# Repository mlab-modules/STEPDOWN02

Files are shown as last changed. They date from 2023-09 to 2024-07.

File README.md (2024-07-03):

# STEPDOWN02 - 1MHz switching down converter

This repository contains the design files, documentation, and usage instructions for the TPS54332 MLAB module. The TPS54332 is a high-efficiency synchronous buck converter capable of delivering up to 3 A of continuous output current. This development module is designed to integrate the TPS54332 into MLAB projects with ease.

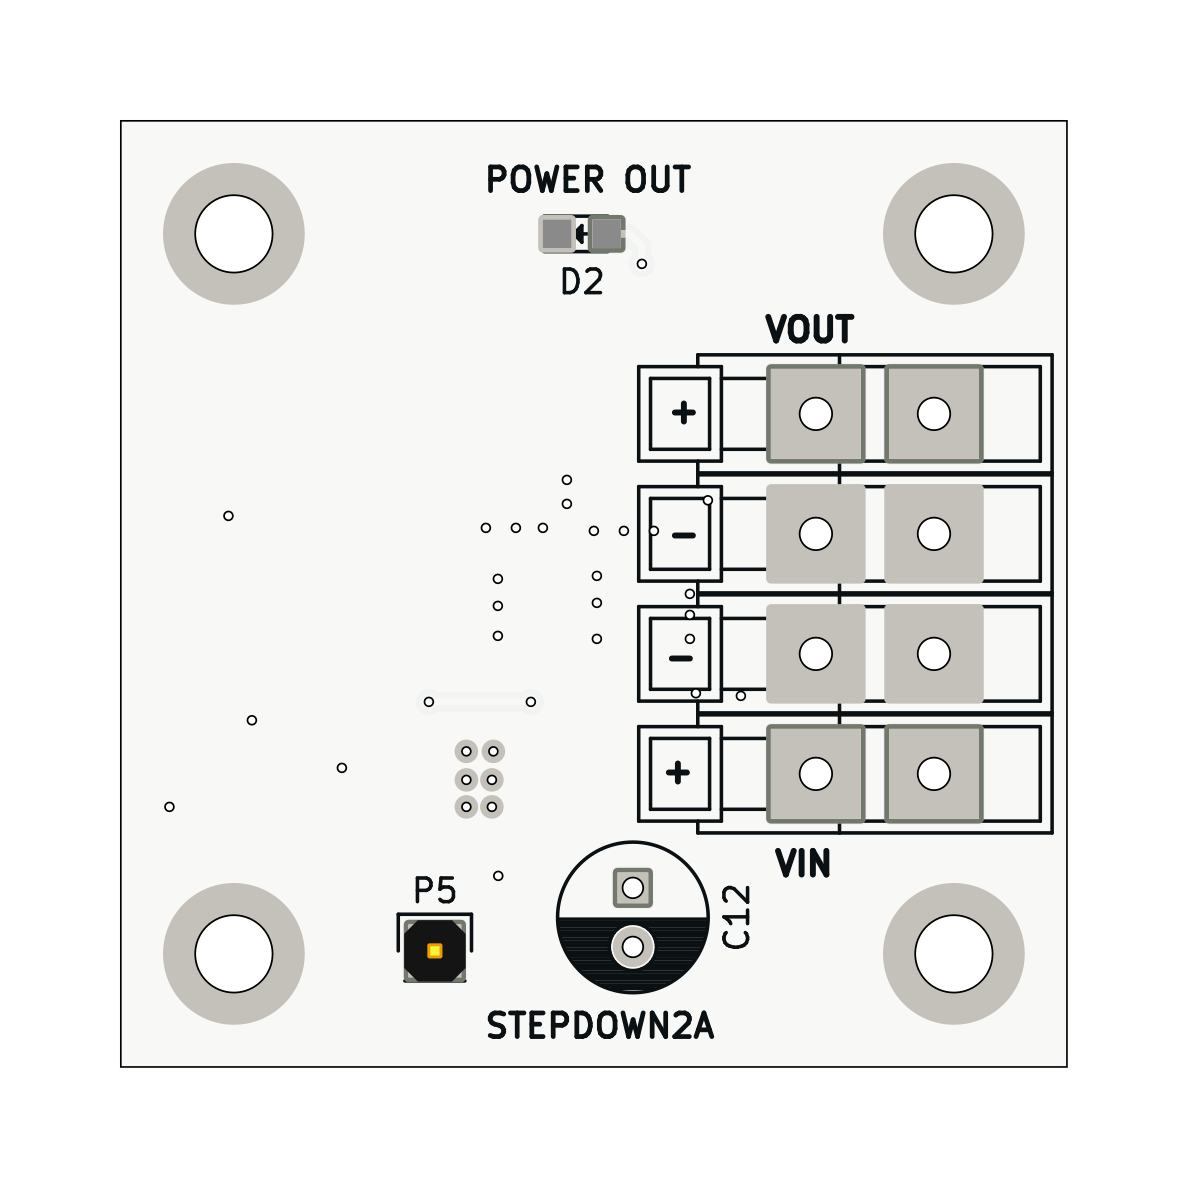
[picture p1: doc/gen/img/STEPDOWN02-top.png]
STEPDOWN02 top view
 

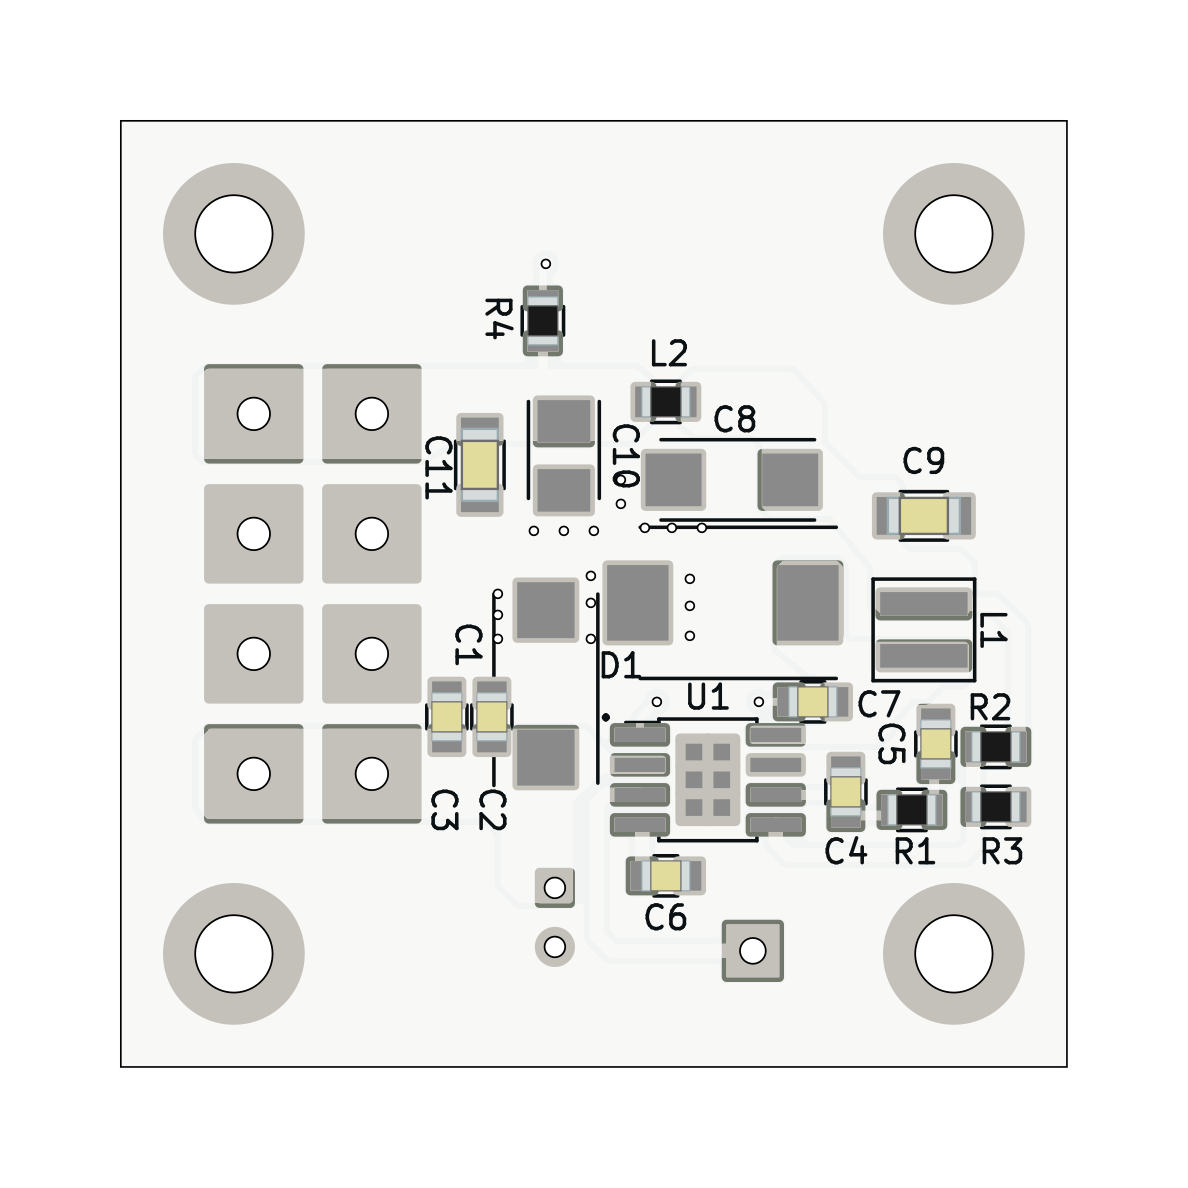
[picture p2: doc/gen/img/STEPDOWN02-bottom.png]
STEPDOWN02 bottom veiw
 

## Features

- **Input Voltage Range**: 3.5 V to 28 V
- **Output Voltage Range**: 0.8 V to 23 V
- **Output Current**: Up to 3 A
- **Efficiency**: Up to 95%
- **Switching Frequency**: Adjustable up to 2 MHz
- **Integrated High-Side and Low-Side MOSFETs**
- **Cycle-by-Cycle Current Limit, Frequency Fold Back and Thermal Shutdown Protection**

## Getting Started

### Prerequisites

To use this development module, you will need:

- A DC power supply (3.5 V to 28 V)
- Load device (up to 3 A)
- Multimeter or oscilloscope for measurements
- Soldering equipment (if customization of output voltage is needed)

### Installation

1. **Connect the Power Supply**: Connect the positive terminal of your DC power supply to the VIN pin and the negative terminal to the GND pin of the module.
2. **Connect the Load**: Connect your load device between the VOUT pin and GND pin of the module.

### Usage

1. **Adjust Output Voltage**: The output voltage can be adjusted by selecting appropriate values for the feedback resistors (R1 and R2). Refer to the datasheet for the resistor calculation formula.
2. **Monitoring**: Use a multimeter or oscilloscope to monitor the output voltage and current.
3. **Optimization**: Fine-tune the switching frequency and compensation network as required for your application.

## Documentation

- **Datasheet**: [TPS54332 Datasheet](https://www.ti.com/product/TPS54332)

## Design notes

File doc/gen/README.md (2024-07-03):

# PCB

Board size: 40.13x40.13 mm (1.58x1.58 inches)

- This is the size of the rectangle that contains the board
- Thickness: 1.6 mm (63 mils)
- Material: FR4
- Finish: HAL
- Layers: 2
- Copper thickness: 35 µm

Solder mask: TOP / BOTTOM

- Color: Green

Silk screen: TOP / BOTTOM

- Color: White

# Important sizes

Clearance: 0.15 mm (6 mils)

Track width: 0.3 mm (12 mils)

- By design rules: 0.2 mm (8 mils)

Drill: 0.4 mm (16 mils)

- Vias: 0.4 mm (16 mils) [Design: 0.4 mm (16 mils)]
- Pads: 0.4 mm (16 mils)
- The above values are real drill sizes, they add 0.1 mm (4 mils) to plated holes (PTH)

Via: 0.6/0.3 mm (24/12 mils)

- By design rules: 0.4/0.3 mm (16/12 mils)
- Micro via: yes [0.2/0.1 mm (8/4 mils)]
- Buried/blind via: yes
- Total: 28 (thru: 28 buried/blind: 0 micro: 0)

Outer Annular Ring: 0.1 mm (4 mils)

- By design rules: 0.1 mm (4 mils)

Eurocircuits class: 6C
- Using min drill 0.35 mm for an OAR of 0.13 mm

# General stats

Components count: (SMD/THT)

- Top: 1/10 (SMD + THT)
- Bottom: 19/0 (SMD)

Defined tracks:

- 0.4 mm (16 mils)
- 0.5 mm (20 mils)
- 0.6 mm (24 mils)
- 0.8 mm (31 mils)
- 1.0 mm (39 mils)
- 1.5 mm (59 mils)
- 2.0 mm (79 mils)
- 2.5 mm (98 mils)

Used tracks:

- 0.3 mm (12 mils) (39) defined: no
- 0.4 mm (16 mils) (12) defined: yes
- 0.5 mm (20 mils) (1) defined: yes
- 0.6 mm (24 mils) (34) defined: yes
- 1.0 mm (39 mils) (14) defined: yes
- 1.5 mm (59 mils) (1) defined: yes
- 2.5 mm (98 mils) (2) defined: yes

Defined vias:

Used vias:

- 0.6/0.3 mm (24/12 mils) (Count: 28, Aspect: 2.7 A) defined: no

Holes (excluding vias):

- 0.3 mm (12 mils) (6)
- 0.8 mm (31 mils) (2)
- 1.02 mm (40 mils) (1)
- 1.3 mm (51 mils) (8)
- 3.2 mm (126 mils) (4)

Oval holes:

Drill tools (including vias and computing adjusts and rounding):

- 0.4 mm (16 mils) (34)
- 0.9 mm (35 mils) (2)
- 1.1 mm (43 mils) (1)
- 1.4 mm (55 mils) (8)
- 3.3 mm (130 mils) (4)

Solder paste stats:

Using a paste with 87.75 % alloy, that has an specific gravity for the alloy of 7.4 g/cm³
and 1.0 g/cm³ for the flux. This paste has an specific gravity of  4.15 g/cm³.

The stencil thickness is  0.12 mm.

| Side | Pads with paste | Area [mm²] | Paste [g] |
|---|---|---|---|
| Top | 2 | 2.87 | 0.01 |
| Bottom | 50 | 103.27 | 0.51 |
| Total  | 52 | 106.14 | 0.53 |

Note: this is just an approximation to the theoretical value. Margins of the solder mask and waste aren't computed.

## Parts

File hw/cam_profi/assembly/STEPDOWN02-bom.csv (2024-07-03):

Component | Description | Part | References | Value | Footprint | Quantity Per PCB | Datasheet
1 |  | C | C4 | 18pF | C_0805 | 1
2 |  | C | C5 | 680pF | C_0805 | 1
3 |  | C | C6 | 8n2 | C_0805 | 1
4 |  | C | C7 | 100n | C_0805 | 1
5 |  | C | C3 | 1u | C_0805 | 1
6 |  | C | C9C11 | 1u5 | C_1206 | 2
7 |  | C | C2 | 3u3 | C_0805 | 1
8 |  | CP | C1 | 22u | TantalC_SizeD_EIA-7343_Reflow | 1
9 |  | CP | C10 | 22u | TantalC_SizeB_EIA-3528_Reflow | 1
10 |  | CP | C8 | 22u | TantalC_SizeC_EIA-6032_Reflow | 1
11 |  | CP | C12 | 47u | C_Radial_D6.3_L11.2_P2.5 | 1
12 |  | D_Schottky | D1 | D_Schottky | DO-214AB | 1
13 |  | Led_Small | D2 | POWER OUT | LED_0805 | 1
14 |  | CONN1_1 | J1J2J3J4 | CONN1_1 | WAGO256 | 4
15 |  | INDUCTOR | L2 | 240nH | R_0805 | 1
16 |  | INDUCTOR | L1 | 4.7uH | Inductor_XAL4030-472MEB | 1
17 |  | CONN_01X01 | P5 | CONN_01X01 | Pin_Header_Straight_1x01 | 1
18 |  | R | R4 | 1k2 | R_0805 | 1
19 |  | R | R3 | 1k93 | R_0805 | 1
20 |  | R | R2 | 10k2 | R_0805 | 1
21 |  | R | R1 | 35k7 | R_0805 | 1
22 |  | TPS54332 | U1 | TPS54332 | 8-PowerSOIC_Pitch1.27mm | 1 | https://www.ti.com/lit/ds/symlink/tps54332.pdf?ts=1720015286104

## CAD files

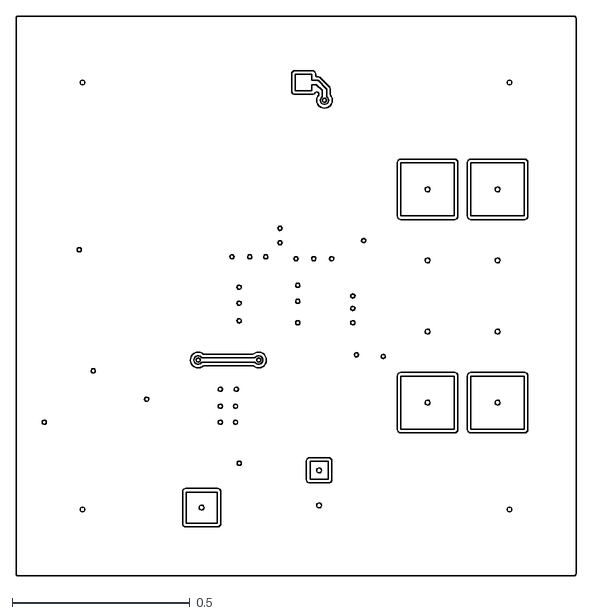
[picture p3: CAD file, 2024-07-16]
doc/gen/dxf/STEPDOWN02-F_Cu.dxf
1.57 x 1.57

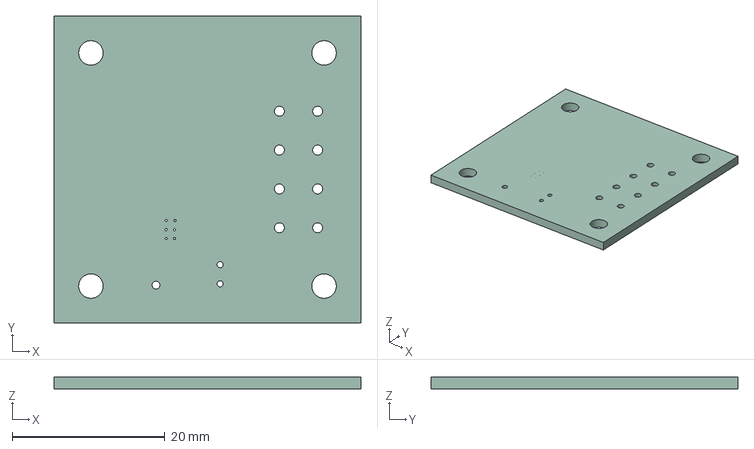
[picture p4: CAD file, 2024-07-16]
doc/gen/STEPDOWN02.step
40.1 x 40.1 x 1.60 mm

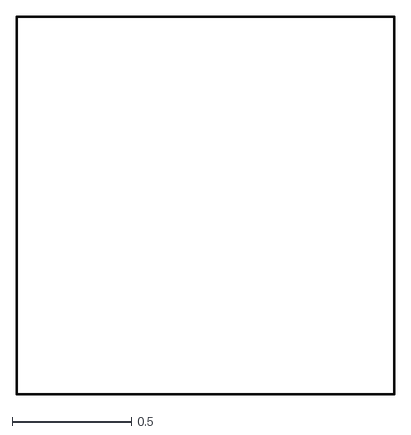
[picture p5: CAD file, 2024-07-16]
doc/gen/dxf/STEPDOWN02-Edge_Cuts.dxf
1.59 x 1.59

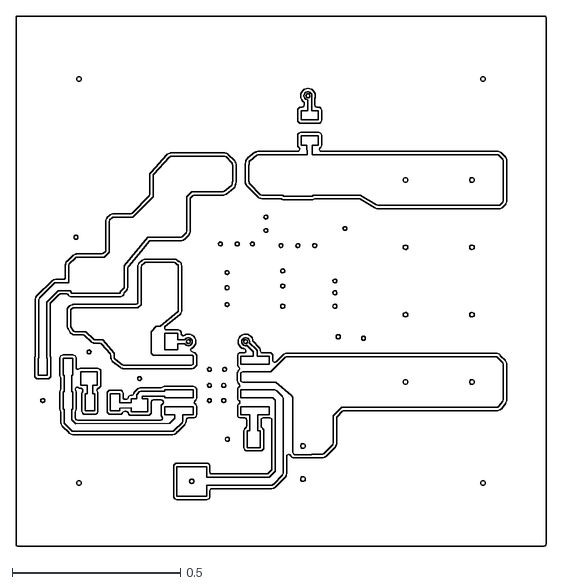
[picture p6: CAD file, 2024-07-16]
doc/gen/dxf/STEPDOWN02-B_Cu.dxf
1.57 x 1.57

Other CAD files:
doc/gen/dxf/STEPDOWN02-User_Drawings.dxf
doc/gen/dxf/STEPDOWN02-B_Mask.dxf
doc/gen/dxf/STEPDOWN02-B_Paste.dxf
doc/gen/dxf/STEPDOWN02-B_Silkscreen.dxf
doc/gen/dxf/STEPDOWN02-F_Mask.dxf
doc/gen/dxf/STEPDOWN02-F_Paste.dxf
doc/gen/dxf/STEPDOWN02-F_Silkscreen.dxf

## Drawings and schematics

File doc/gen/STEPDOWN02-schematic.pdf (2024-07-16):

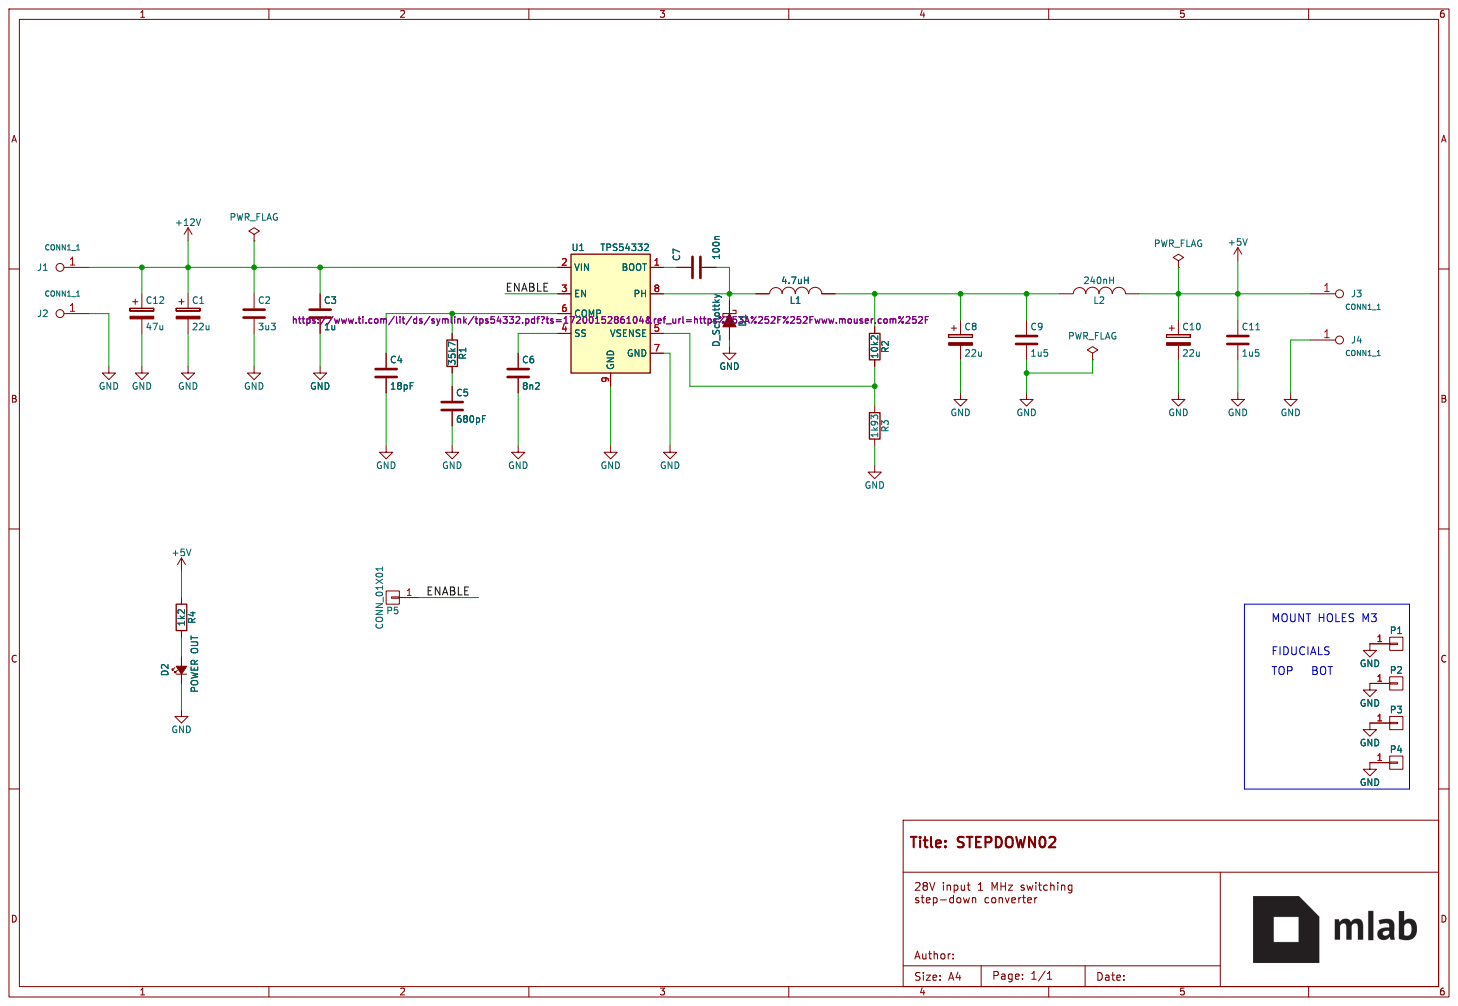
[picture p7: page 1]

https://www.ti.com/lit/ds/symlink/tps54332.pdf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 D1 D_Schottky GND

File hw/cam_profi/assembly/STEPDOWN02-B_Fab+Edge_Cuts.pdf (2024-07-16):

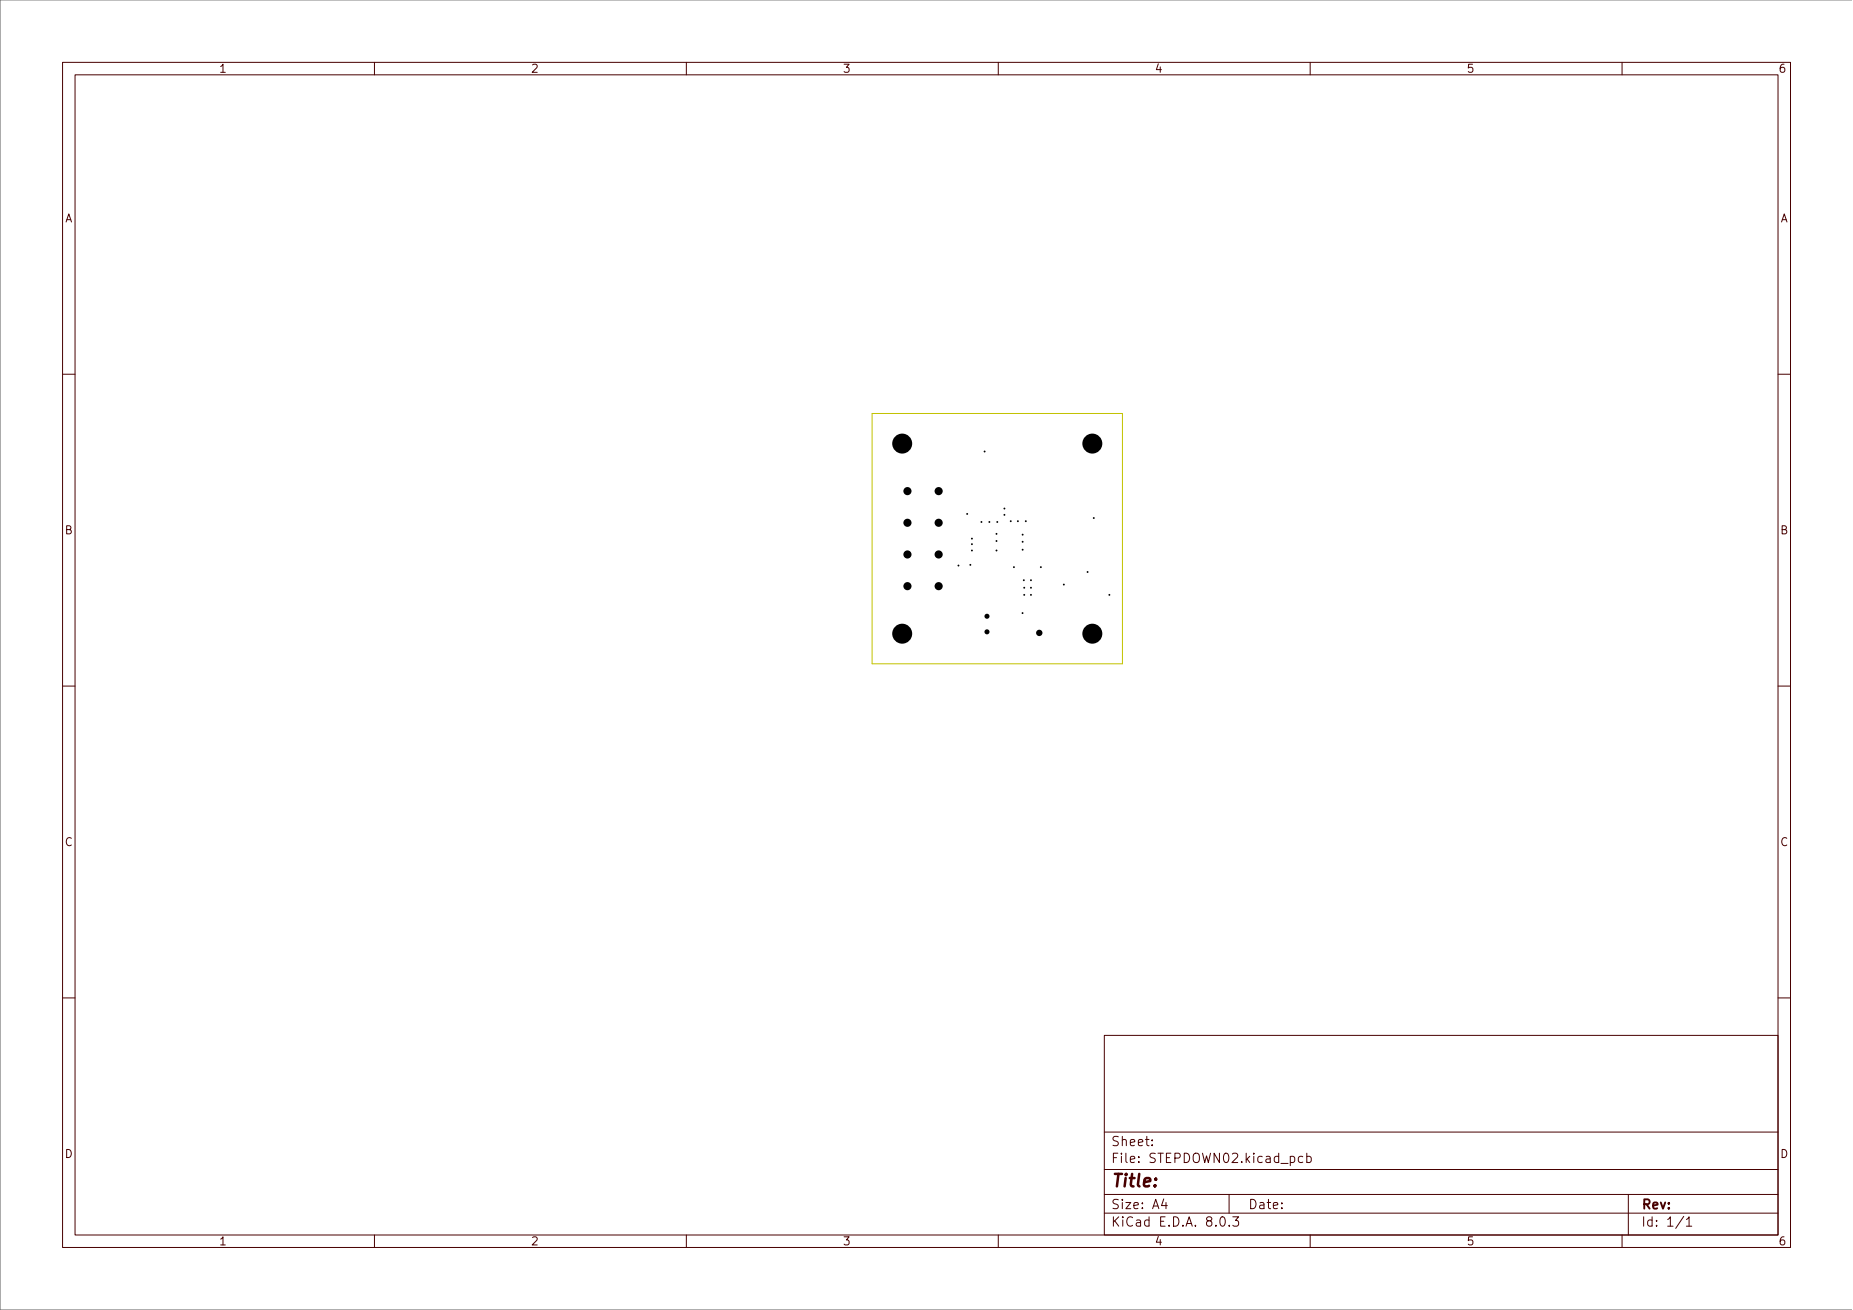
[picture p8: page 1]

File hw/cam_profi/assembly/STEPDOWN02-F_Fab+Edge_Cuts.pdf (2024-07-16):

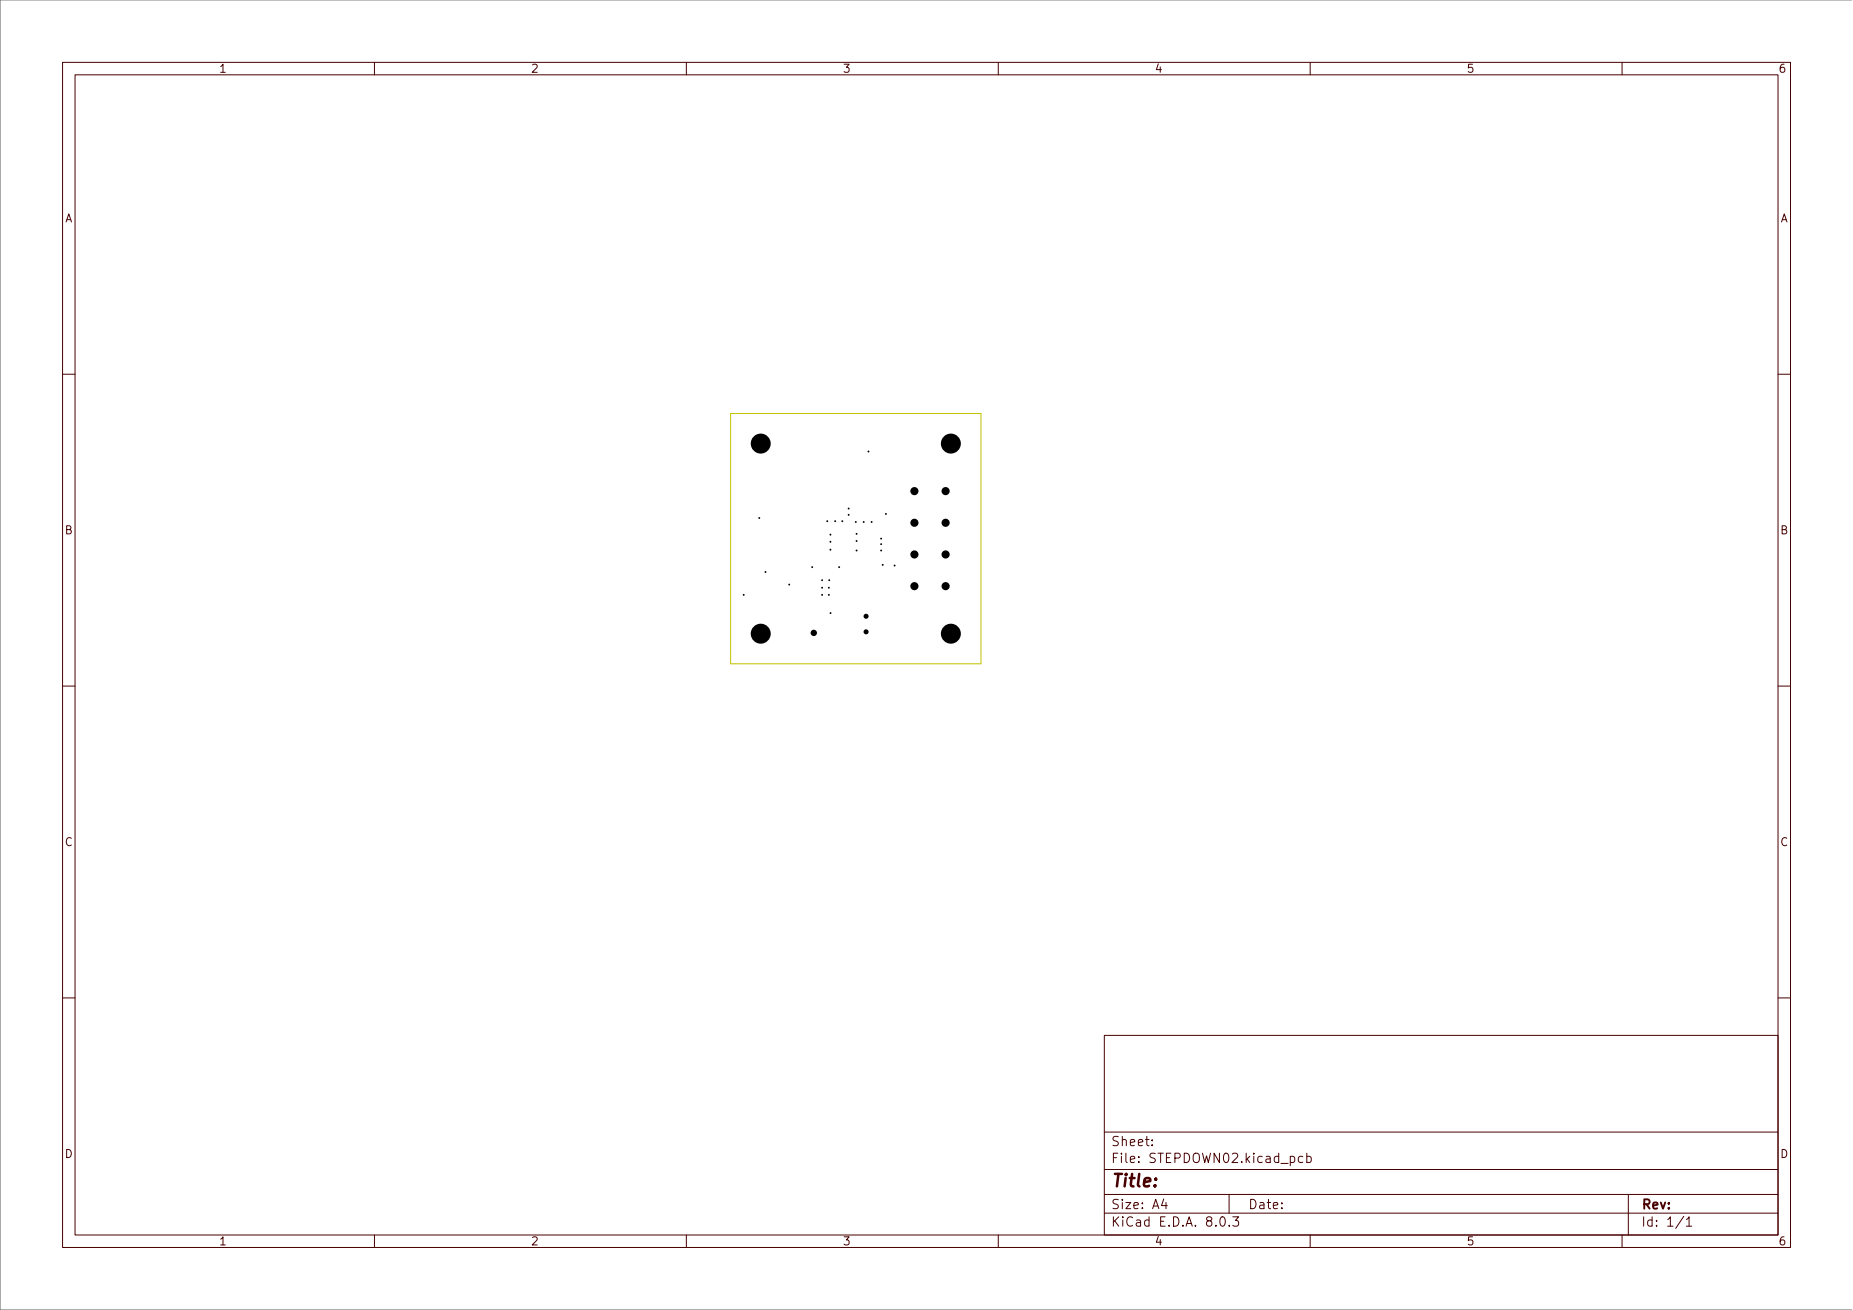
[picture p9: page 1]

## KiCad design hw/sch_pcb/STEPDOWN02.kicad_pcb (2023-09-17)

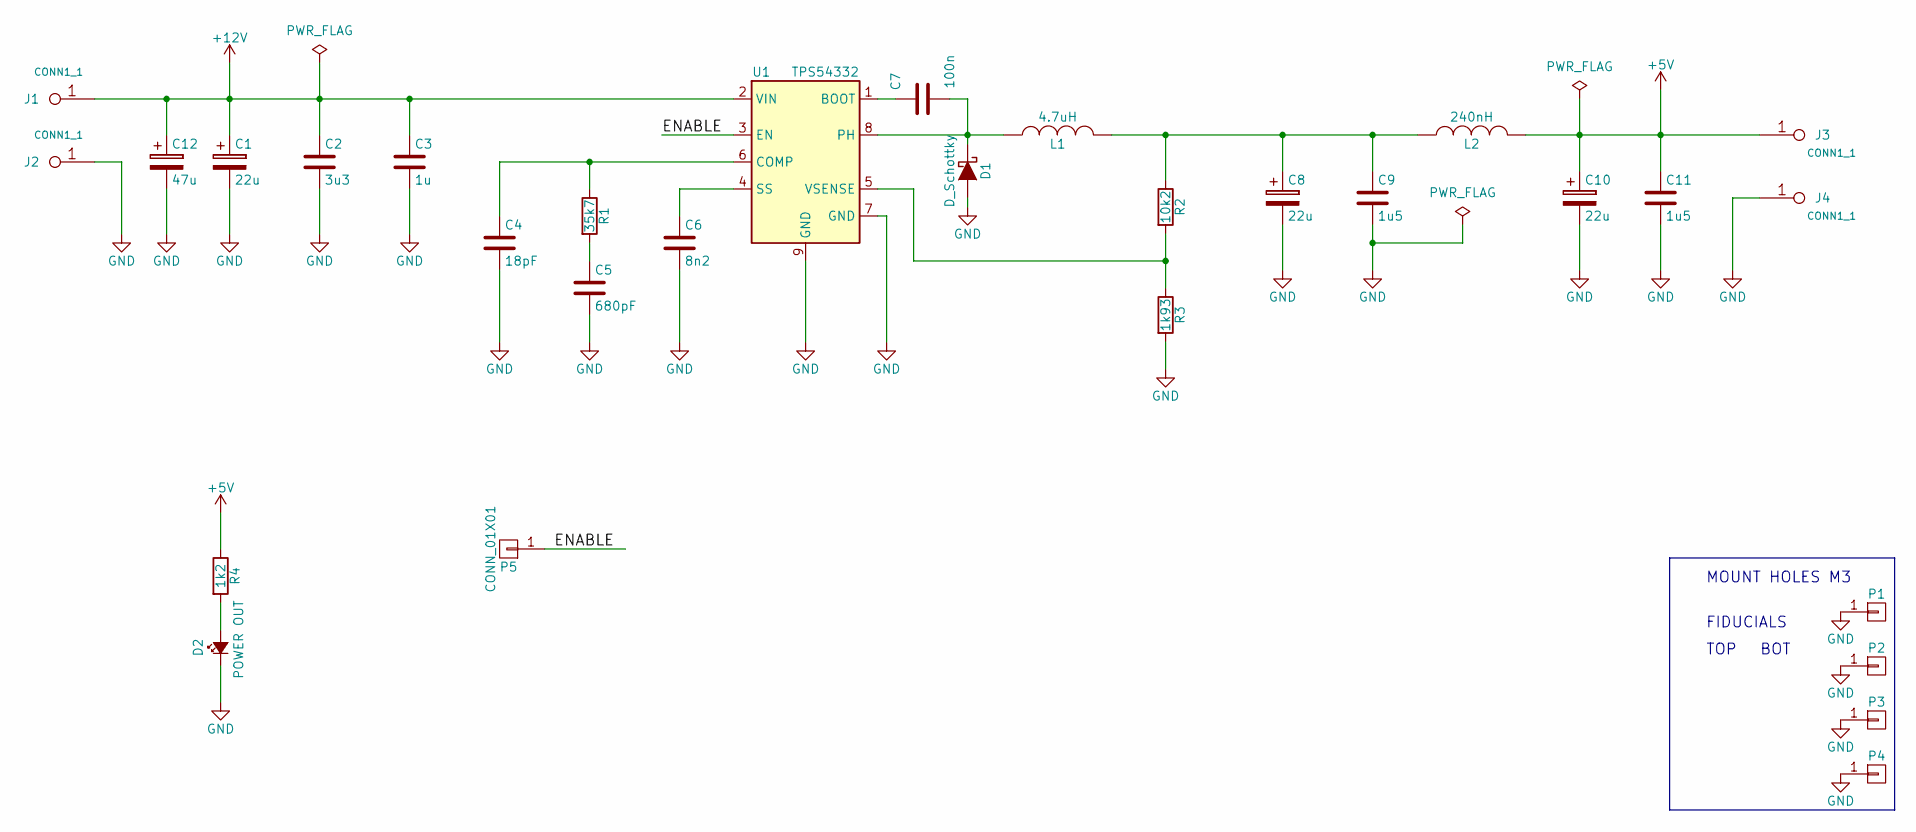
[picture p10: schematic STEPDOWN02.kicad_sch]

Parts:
C1: 22u; TantalC_SizeD_EIA-7343_Reflow
C2: 3u3; C_0805
C3: 1u; C_0805
C4: 18pF; C_0805
C5: 680pF; C_0805
C6: 8n2; C_0805
C7: 100n; C_0805
C8: 22u; TantalC_SizeC_EIA-6032_Reflow
C9, C11: 1u5; C_1206
C10: 22u; TantalC_SizeB_EIA-3528_Reflow
C12: 47u; C_Radial_D6.3_L11.2_P2.5
D1: D_Schottky; DO-214AB
D2: POWER OUT; LED_0805
J1, J2, J3, J4: CONN1_1; WAGO256
L1: 4.7uH; Inductor_XAL4030-472MEB
L2: 240nH; R_0805
P1, P2, P3, P4: _NC; MountingHole_3.2mm_M3_DIN965_Pad
P5: CONN_01X01; Pin_Header_Straight_1x01
R1: 35k7; R_0805
R2: 10k2; R_0805
R3: 1k93; R_0805
R4: 1k2; R_0805
U1: TPS54332; 8-PowerSOIC_Pitch1.27mm

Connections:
+5V: C10.1, C11.1, J3.1, L2.2, R4.1
+12V: C1.1, C2.1, C3.1, C12.1, J1.1, U1.2 (VIN)
/ENABLE: P5.1, U1.3 (EN)
GND: C1.2, C2.2, C3.2, C4.2, C5.2, C6.2, C8.2, C9.2, C10.2, C11.2, C12.2, D1.2 (A), D2.1 (K), J2.1, J4.1, P1.1, P2.1, P3.1, P4.1, R3.2, U1.7 (GND), U1.9 (GND)
unnamed: C4.1, R1.1, U1.6 (COMP)
unnamed: C5.1, R1.2
unnamed: C6.1, U1.4 (SS)
unnamed: C7.1, D1.1 (K), L1.1, U1.8 (PH)
unnamed: C7.2, U1.1 (BOOT)
unnamed: C8.1, C9.1, L1.2, L2.1, R2.1
unnamed: D2.2 (A), R4.2
unnamed: R2.2, R3.1, U1.5 (VSENSE)

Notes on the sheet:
BOT
FIDUCIALS
TOP
MOUNT HOLES M3

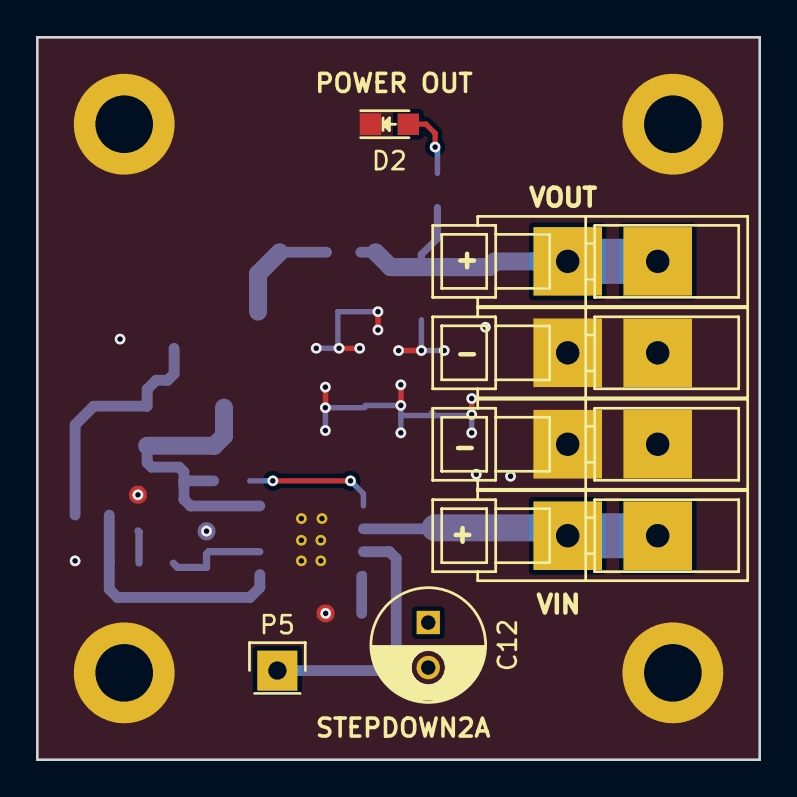
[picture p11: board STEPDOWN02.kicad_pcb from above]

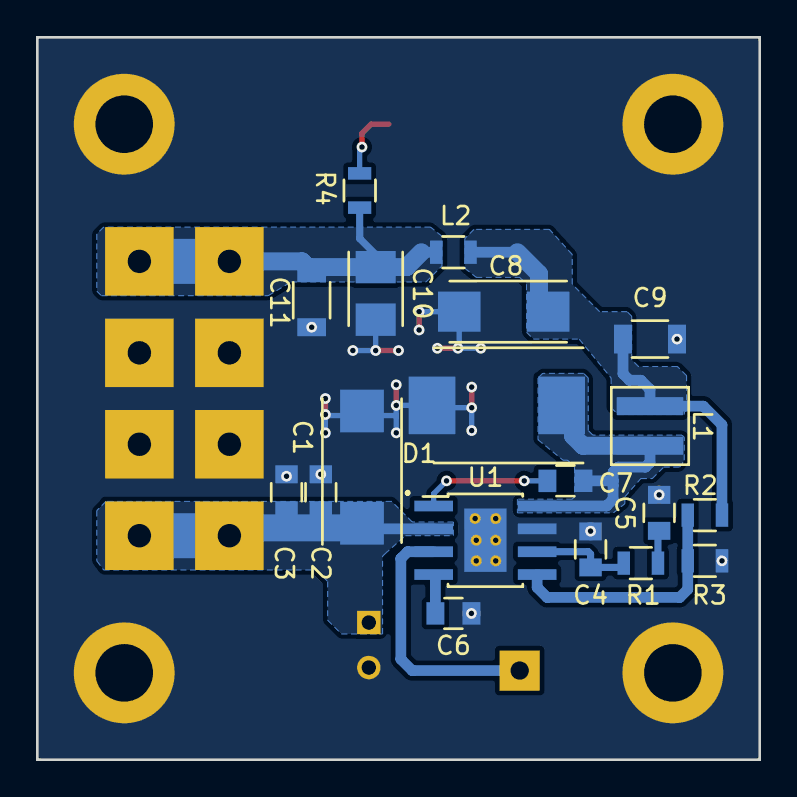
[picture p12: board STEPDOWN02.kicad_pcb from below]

Board: 2 copper layers, 40.1 x 40.1 mm, 30 parts (19 on the bottom side), 12 nets.

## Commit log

2020-12-05 Initial commit.
    [STEPDOWN2A-2020-07-08-12-35-27.sch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]
2023-09-17 Convert project to KiCAD7 format.
    [STEPDOWN02.kicad_pcb, STEPDOWN02.kicad_sch, STEPDOWN2A-2020-07-08-12-35-27.sch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]
2023-09-17 Update actions products
    [STEPDOWN02-B_Cu.dxf, STEPDOWN02-B_Mask.dxf, STEPDOWN02-B_Paste.dxf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]
2024-07-03 Update module readme.
    [STEPDOWN02.kicad_sch]
